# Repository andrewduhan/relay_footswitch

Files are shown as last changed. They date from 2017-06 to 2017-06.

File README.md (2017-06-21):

# relay_footswitch
Control your amp's reverb with a low-voltage relay
================

Tap your 6.3V heater rail to control a relay - switch your reverb on and off with low-voltage DC, instead of sending your tone through a long antenna on the floor!

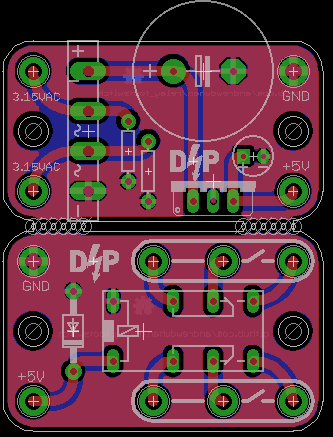
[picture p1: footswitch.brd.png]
Printed Board


Designed as two break-apart boards, one to provide 5V DC from the 6.3VAC heater rail, and a breakout board for the DPDT relay.
Inputs and outputs are sized to accept turret lugs (tubedepot part "BP-TURRET").
Generate 5VDC and send it down the wire to your footswitch.  Leave your signal and tone where it belongs - inside your amp chassis.

#BOM
- relay:              Omron G6A-234P-ST-US-DC5
- big cap:            4700uF 35V Nichicon
- little cap:         Optional, whatever you want really
- bridge rectifier:   Rectron BR305 
- diode:              1N4001 
- vreg:               7805

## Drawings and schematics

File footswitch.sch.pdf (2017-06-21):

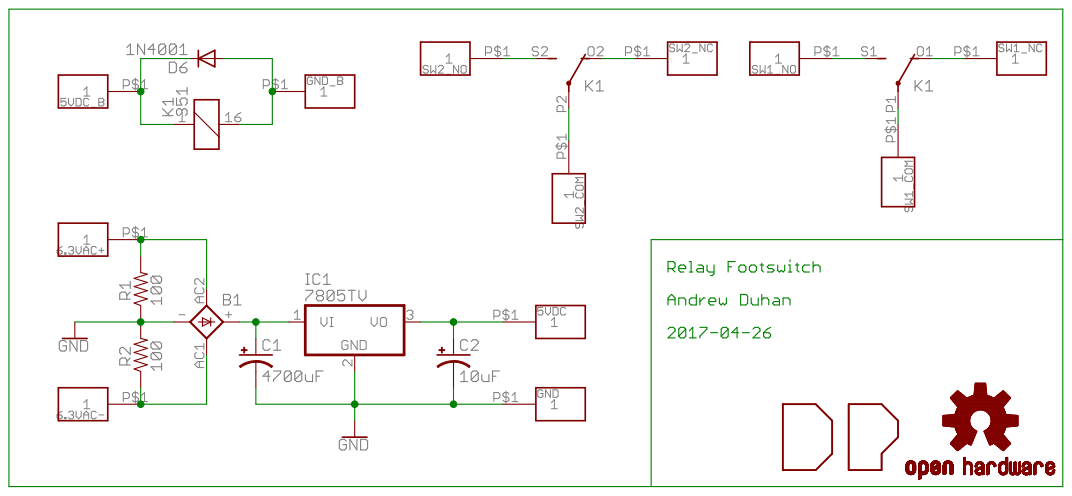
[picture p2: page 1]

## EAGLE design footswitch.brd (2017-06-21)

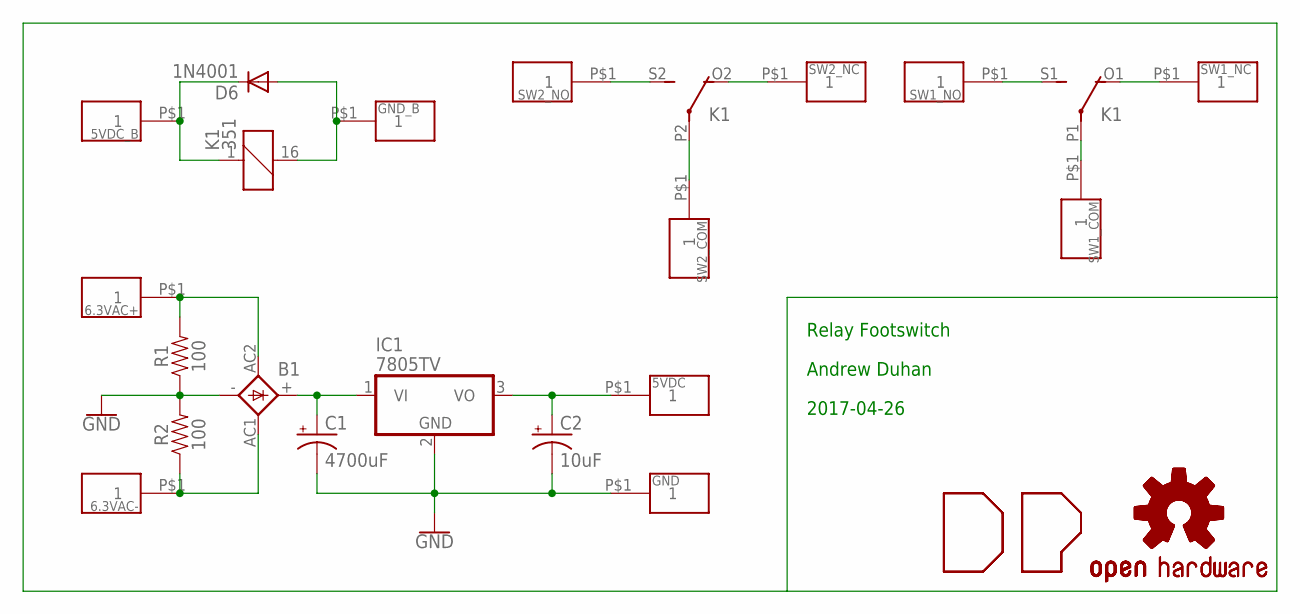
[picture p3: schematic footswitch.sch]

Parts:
5VDC, 5VDC_B, 6.3VAC+, 6.3VAC-: TURRET_LUG_1540
B1: GBU4; GBU4S
C1: 4700uF; E7,5-18
C2: 10uF; CPOL-RADIAL-2.5MM-5MM
D6: 1N4001; DO41-10
GND: TURRET_LUG_1540
GND_B: TURRET_LUG_1540
IC1: 7805TV; TO220V
K1: 351
LOGO1, LOGO2: OSHW-LOGOMINI; OSHW-LOGO-MINI
R1, R2: 100; AXIAL-0.3
SW1_COM, SW1_NC, SW1_NO, SW2_COM, SW2_NC, SW2_NO: TURRET_LUG_1540
U$1, U$2: DP_LOGO

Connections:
5VDC: 5VDC.P$1, C2.1 (+), IC1.3 (VO)
5VDC_B: 5VDC_B.P$1, D6.C, K1.1
GND: B1.-, C1.-, C2.2 (-), GND.P$1, IC1.2 (GND), R1.P$1 (1), R2.P$2 (2)
GND_B: D6.A, GND_B.P$1, K1.16 (2)
unnamed: B1.+, C1.+, IC1.1 (VI)
unnamed: 6.3VAC+.P$1, B1.AC2 (AC1), R1.P$2 (2)
unnamed: 6.3VAC-.P$1, B1.AC1 (AC2), R2.P$1 (1)
unnamed: K1.P2, SW2_COM.P$1
unnamed: K1.O2 (O), SW2_NC.P$1
unnamed: K1.S2 (S), SW2_NO.P$1
unnamed: K1.O1 (O), SW1_NC.P$1
unnamed: K1.S1 (S), SW1_NO.P$1
unnamed: K1.P1, SW1_COM.P$1

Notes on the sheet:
Relay Footswitch
Andrew Duhan
2017-04-26

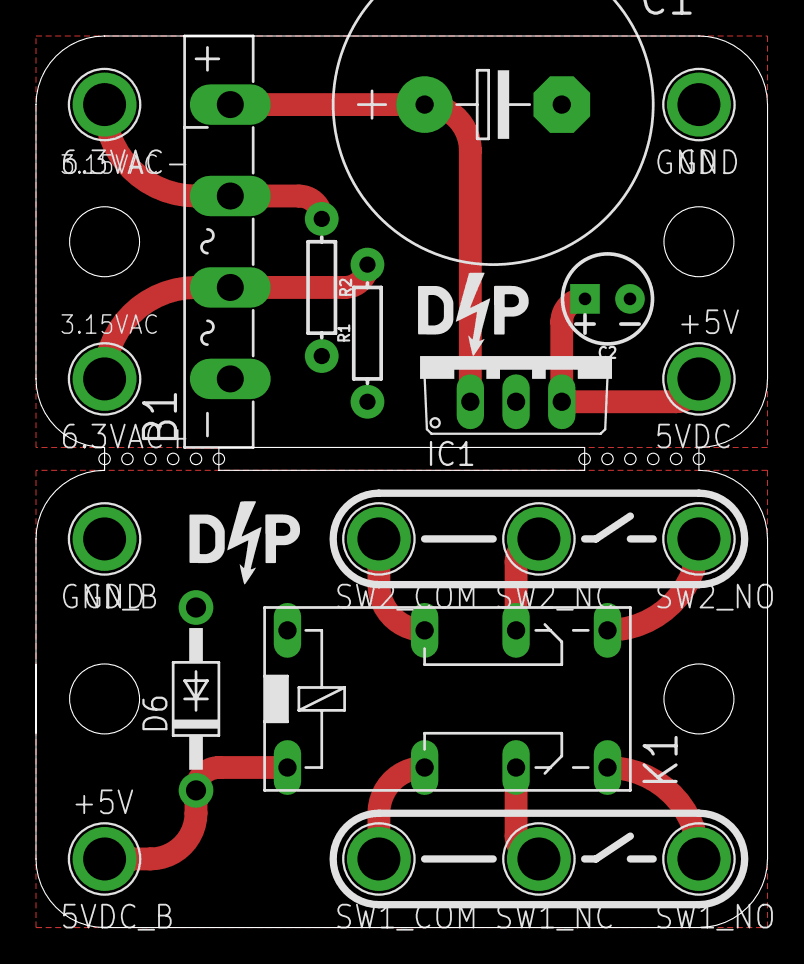
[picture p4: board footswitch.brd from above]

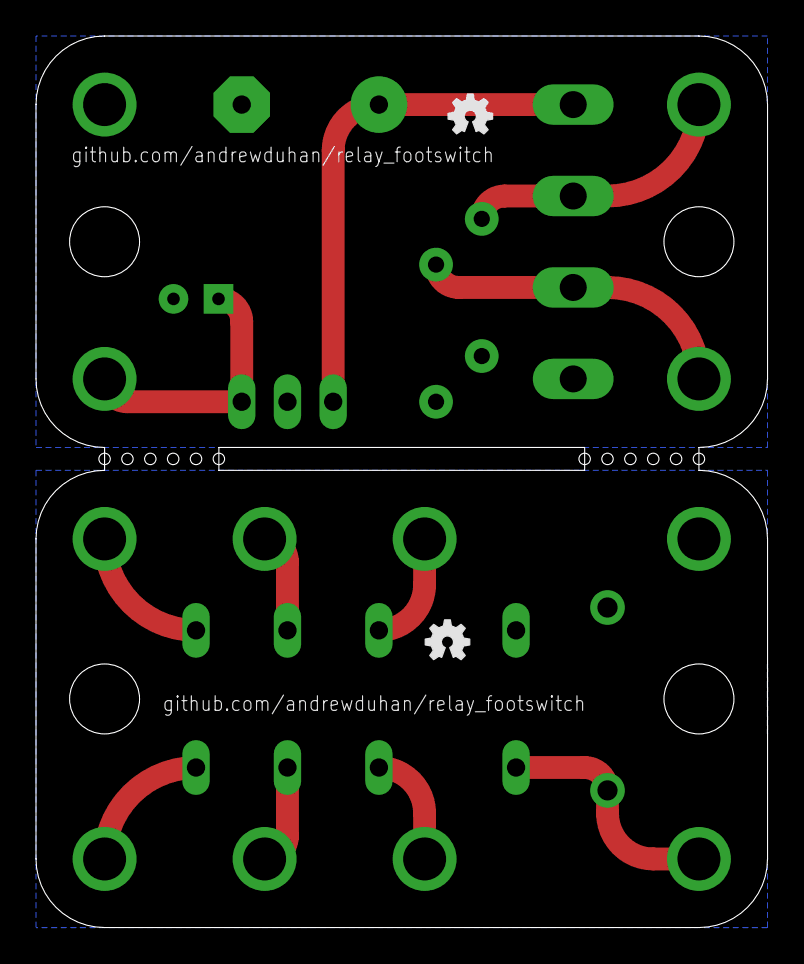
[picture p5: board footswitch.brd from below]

Board: 2 copper layers, 40.6 x 49.5 mm, 24 parts (2 on the bottom side), 13 nets.

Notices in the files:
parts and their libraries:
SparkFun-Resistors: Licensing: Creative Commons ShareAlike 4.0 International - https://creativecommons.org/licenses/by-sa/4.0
